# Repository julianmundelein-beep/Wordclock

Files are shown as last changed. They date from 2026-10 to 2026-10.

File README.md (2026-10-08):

# Wordclock

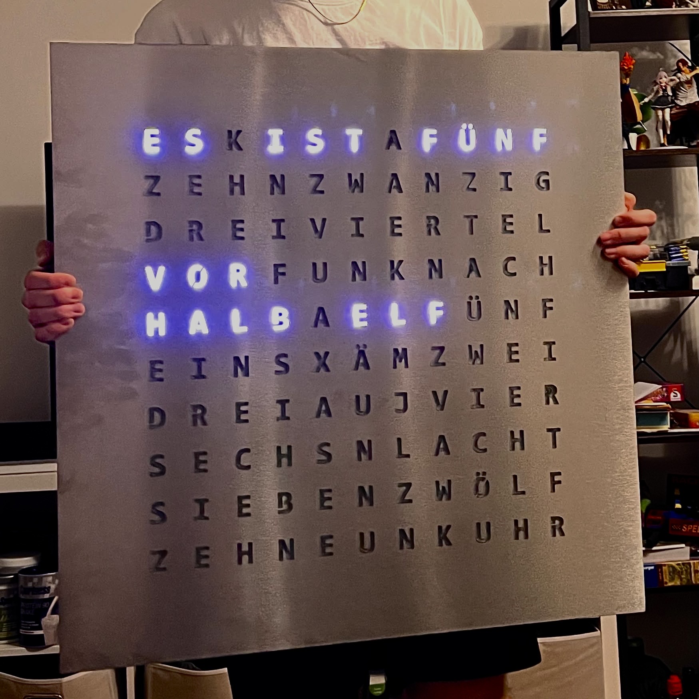
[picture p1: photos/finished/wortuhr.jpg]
Finished word clock


My self-built word clock with a laser-cut stainless-steel front. In the photo it reads „ES IST FÜNF VOR HALB ELF“.

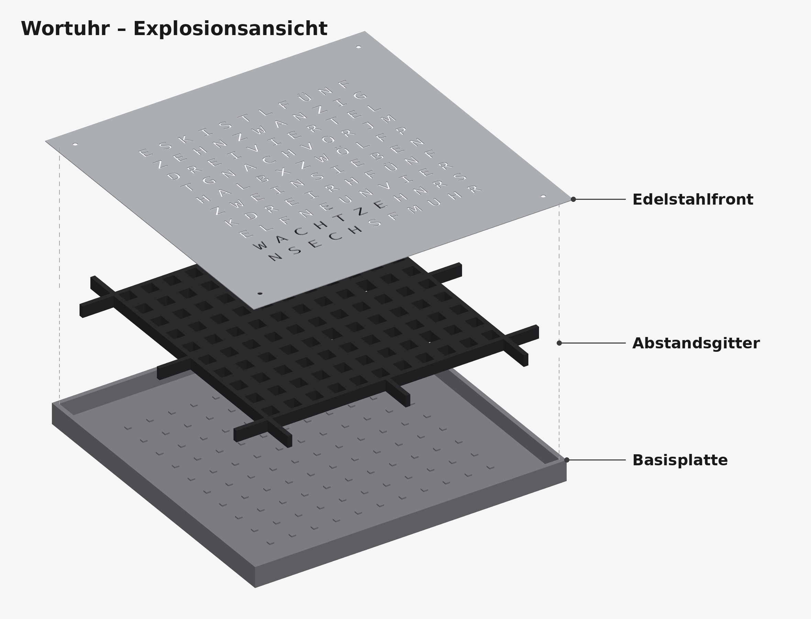
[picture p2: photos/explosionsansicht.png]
Exploded view


## Front panel

[`fabrication/stainless-front-panel/EdelstahlFrontV6.dxf`](fabrication/stainless-front-panel/)

Stainless-steel front, 697.5 × 697.5 mm, with a German 11 × 10 letter grid. I drew it in Fusion 360 and exported it as DXF for laser cutting.

## CAD assembly

[`cad/GesamtModell.step`](cad/GesamtModell.step)

STEP export of the full assembly from Fusion 360, with two parts:

- **Basisplatte**: base plate that holds the LED strips
- **Abstandsgitter**: spacer grid between the LEDs and the front, so each letter is lit separately

## Electronics

[`electronics/schematic/`](electronics/schematic/)

Schematic

- **Controller:** Wemos D1 mini (ESP8266)
- **LEDs:** addressable 5 V LED strip
- **Level shifter:** 74HCT125 with a 220 Ω series resistor, data from `RX`/GPIO3
- **Power:** Mean Well GST60A05-P1J, 5 V

The folder also has the bill of materials, the wiring table and my original hand sketch.

## Firmware

[OpenWordClock-Software](https://github.com/openclock/OpenWordClock-Software), built with PlatformIO. The hardware-relevant settings are listed in [`firmware/`](firmware/).

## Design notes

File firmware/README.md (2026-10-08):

# Firmware

The software source for this project is the [OpenWordClock-Software repository](https://github.com/openclock/OpenWordClock-Software), a fork of [ESPWortuhr/Wortuhr](https://github.com/ESPWortuhr/Wortuhr). It is built with PlatformIO; the ESP8266 environment is `nodemcuv3`.

## Settings relevant to this hardware

From `include/config.h` in my local checkout:

| Setting | Value | Meaning |
| --- | --- | --- |
| `LED_PIN` | `3` | LED data on `RX`/GPIO3, matches the [schematic](../electronics/schematic/) |
| `Wire.begin(D4, D3)` (in `src/Wortuhr.cpp`) | SDA = D4, SCL = D3 | I²C pins for the RTC on the ESP8266 |
| `RTC_Type` | `RTC_DS3231` | External RTC type |
| `DEFAULT_LAYOUT` | `Ger10x11` | German front, 10 rows × 11 LEDs + 4 minute LEDs |
| `MINUTE_LED4x` | defined | 4 separate minute LEDs |
| `MEANDER_ROWS` | `true` | LED strip runs in a serpentine pattern |

Most of these can also be changed later in the clock's web interface.

TODO: Record the exact upstream revision flashed to the clock and any further project-specific changes. The upstream repository's README describes the software as BSD-3 licensed; preserve its applicable copyright and license notices if source files are copied here.

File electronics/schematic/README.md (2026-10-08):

# Schematic

Schematic

| File | Contents |
| --- | --- |
| [`schaltplan.svg`](schaltplan.svg) / [`schaltplan.png`](schaltplan.png) | Clean schematic (vector / raster) |
| [`schaltplan_skizze.png`](schaltplan_skizze.png) | Original hand-drawn sketch with parts list |
| [`bom.csv`](bom.csv) | Bill of materials |

The schematic was redrawn by hand as SVG from the sketch; there is no EDA source file.

## How it works

- **Power:** The 5 V supply (J1) feeds a common +5 V rail for the ESP, the level shifter and the LEDs via fuse F1 and switch S1.
- **Buffering:** C1 (1000 µF) absorbs inrush current and LED load steps.
- **Data line:** The ESP8266 runs at 3.3 V, the LEDs expect 5 V logic. The 74HCT125 (U2) lifts the signal from `RX`/GPIO3 to 5 V (HCT input: V<sub>IH</sub> ≥ 2.0 V). Only gate 1 is used; `1OE` is tied to GND, so the output is always enabled.
- **R1 (220 Ω)** in series with the data line damps reflections and protects the first LED input.

## Bill of materials

| Ref. | Part | Value / type | Status |
| --- | --- | --- | --- |
| J1 | Power supply | Mean Well GST60A05-P1J, 5 V / 6 A | ✅ available |
| F1 | Fuse | 10 A slow-blow | ❌ missing |
| S1 | Switch | On/off | ✅ available |
| C1 | Electrolytic capacitor | 1000 µF, ≥ 6.3 V | ✅ available |
| U1 | Microcontroller | Wemos D1 mini (ESP8266) | ✅ available |
| U2 | Level shifter | 74HCT125 | ✅ available |
| R1 | Resistor | 220 Ω | ✅ available |
| LED1…n | LED strip | addressable, 5 V | ✅ available |
| U3 | Real-time clock | DS3231 RTC module | ❌ missing (not yet in the schematic) |

## Wiring

| From | To | Net |
| --- | --- | --- |
| J1 + | F1 → S1 → +5 V rail | +5 V |
| +5 V | U1 `5V`, U2 pin 14 (VCC), LED `+5V`, C1 + | +5 V |
| J1 − | U1 `G`, U2 pin 7 (GND), U2 pin 1 (`1OE`), LED `GND`, C1 − | GND |
| U1 `RX` (GPIO3) | U2 pin 2 (`1A`) | Data 3.3 V |
| U2 pin 3 (`1Y`) | R1 → LED `DIN` | Data 5 V |

The data pin matches the firmware (`LED_PIN 3`, see [`firmware/`](../../firmware/)).

## Open points

- [ ] Get **fuse F1** and place it directly after J1.
- [ ] Add the **DS3231 RTC**. The firmware starts I²C on the ESP8266 with `Wire.begin(D4, D3)`, so SDA → `D4` (GPIO2) and SCL → `D3` (GPIO0), supply 3.3 V. Both pins are boot-strapping pins; the module's pull-ups keep them high at boot, which is what the ESP8266 needs.
- [ ] Tie off the **unused 74HCT125 gates** (do not leave CMOS inputs floating): `2OE`, `3OE`, `4OE` (pins 4, 10, 13) to +5 V, `2A`, `3A`, `4A` (pins 5, 9, 12) to GND.
- [ ] Add a **100 nF ceramic capacitor** directly between U2 pin 14 and pin 7.

## Notes

- `RX`/GPIO3 is also the ESP8266's UART receive pin, so serial input over USB is not usable; flashing still works. GPIO3 is the DMA pin of the NeoPixelBus library and gives clean timing.
- The D1 mini is powered directly from the 5 V rail via its `5V` pin. When flashing over USB, switch the supply off (S1) so USB and PSU 5 V do not back-feed each other.
- With many LEDs, feed 5 V into the far end of the strip as well (power injection) to limit voltage drop.

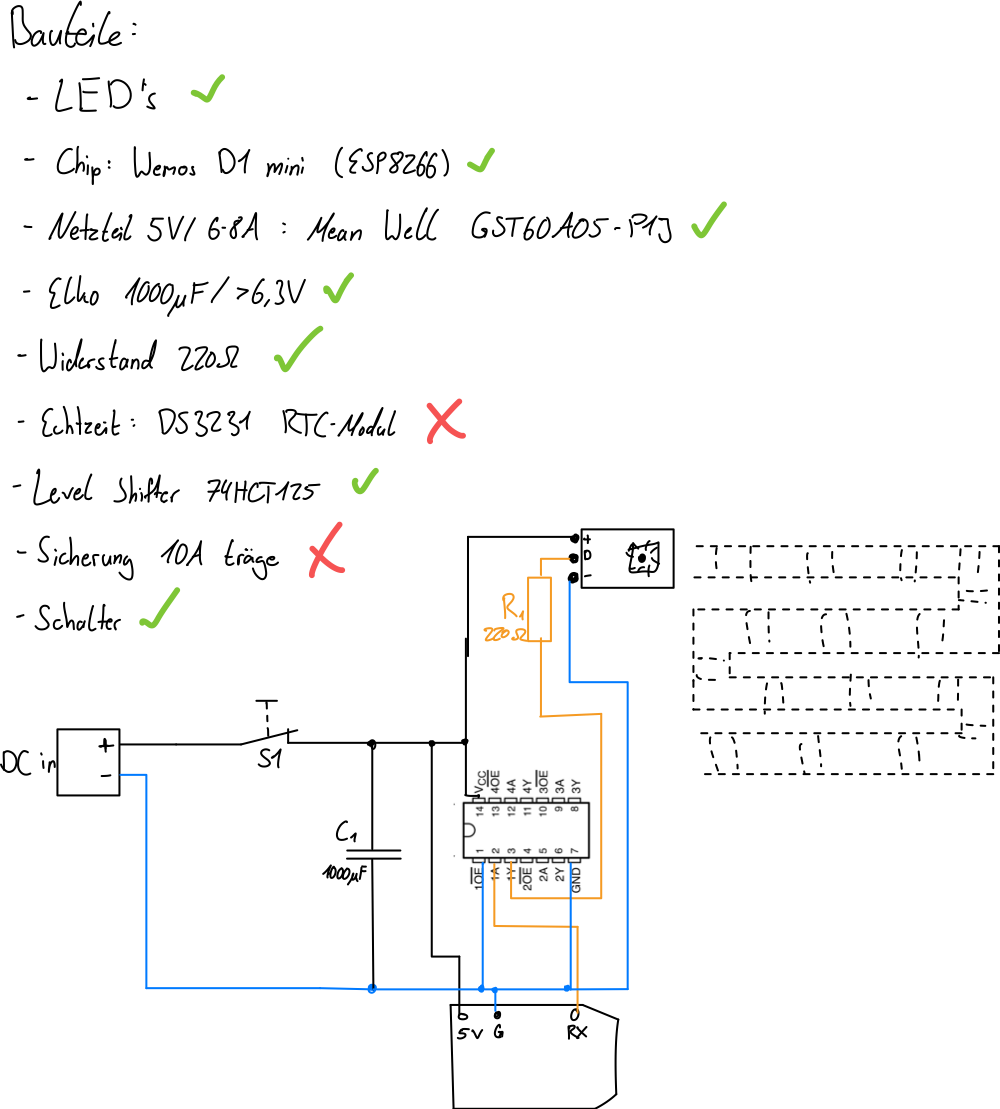
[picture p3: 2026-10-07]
electronics/schematic/schaltplan_skizze.png

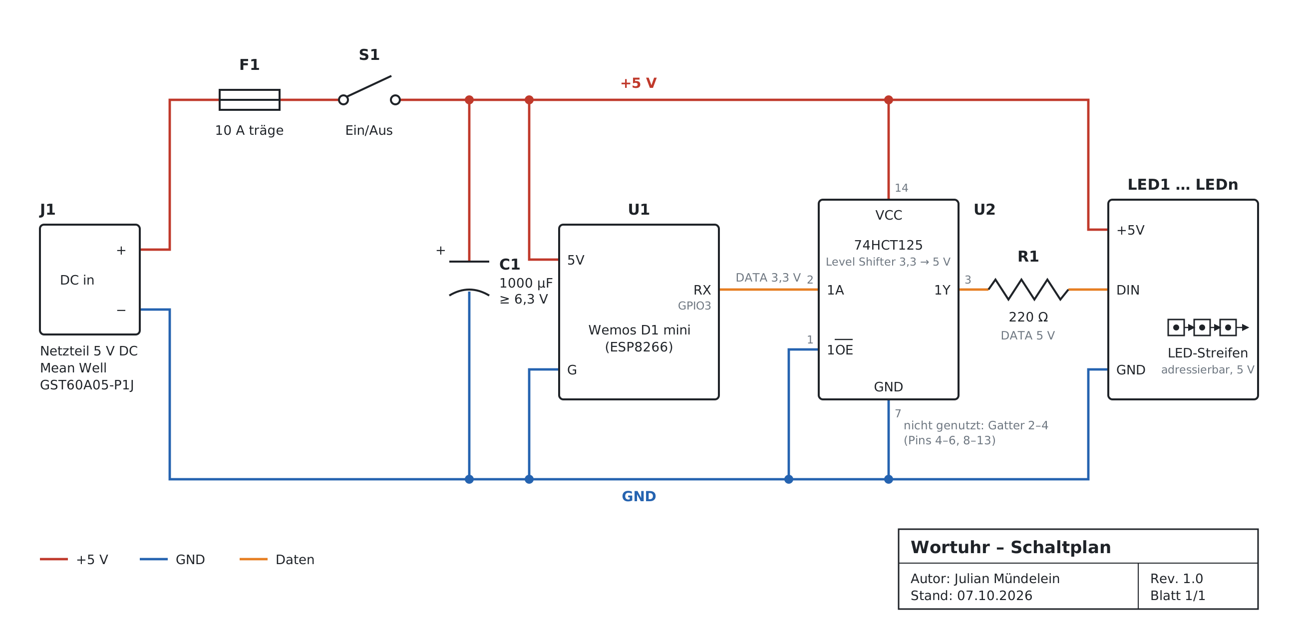
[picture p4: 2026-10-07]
electronics/schematic/schaltplan.png

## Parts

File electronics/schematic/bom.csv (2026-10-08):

Ref | Part | Value/Type | Qty | Status
J1 | Power supply | Mean Well GST60A05-P1J (5 V / 6 A) | 1 | available
F1 | Fuse | 10 A slow-blow | 1 | missing
S1 | Switch | On/Off | 1 | available
C1 | Electrolytic capacitor | 1000 uF / >= 6.3 V | 1 | available
U1 | Microcontroller | Wemos D1 mini (ESP8266) | 1 | available
U2 | Level shifter | 74HCT125 | 1 | available
R1 | Resistor | 220 Ohm | 1 | available
LED1..n | LED strip | addressable 5 V | 1 | available
U3 | Real-time clock | DS3231 RTC module | 1 | missing

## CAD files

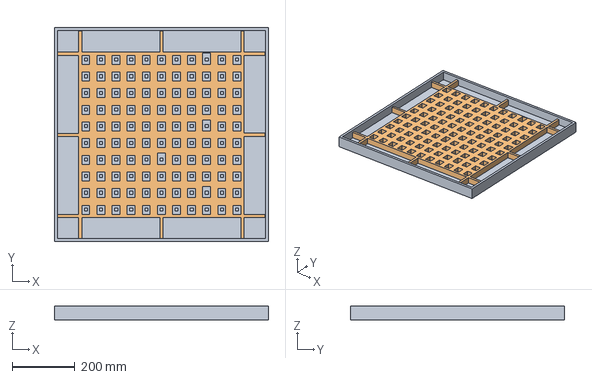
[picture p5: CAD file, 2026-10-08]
cad/GesamtModell.step
680.0 x 680.0 x 45.0 mm
Basisplatte
Abstandsgitter (v6~recovered)

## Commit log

2026-10-07 Hardware-Doku: Schaltplan, Stückliste und README
    [stueckliste.csv]
2026-10-08 Restructure repo; add schematic, BOM and firmware notes
    [bom.csv, stueckliste.csv]
2026-10-08 Add photo, exploded view and CAD model; slim down README
    [GesamtModell.step]
